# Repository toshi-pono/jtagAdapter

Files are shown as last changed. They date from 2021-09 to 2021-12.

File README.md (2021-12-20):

# JtagAdapter

jtag adapter using FT232H  
Created during the Security Camp 2021 X-2 track

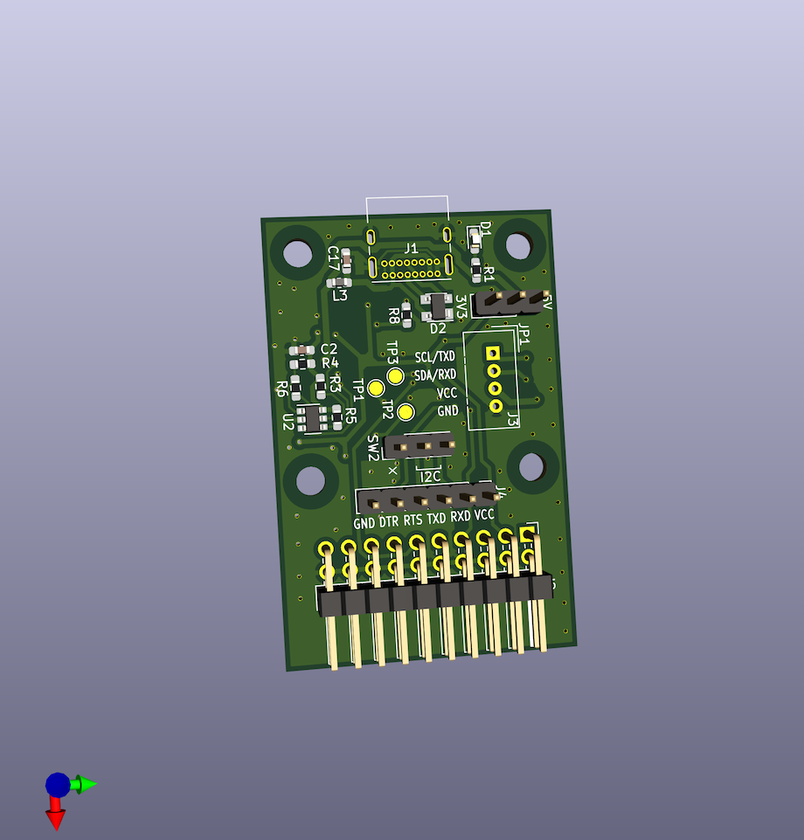
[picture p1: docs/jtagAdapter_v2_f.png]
JtagAdapter_v2_front
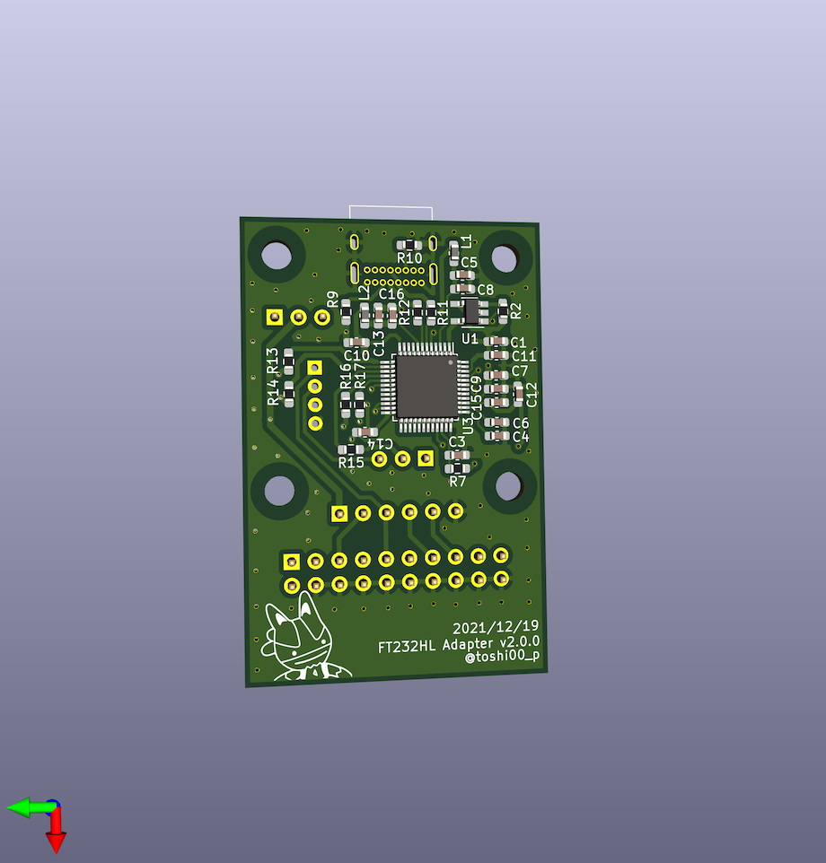
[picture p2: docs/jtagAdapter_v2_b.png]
JtagAdapter_v2_back


## License

SiT2001B-MEMS-Clock-Generator symbol is based on https://github.com/asukiaaa/kicad-symbols-asukiaaa

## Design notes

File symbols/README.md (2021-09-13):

Using https://github.com/asukiaaa/kicad-symbols-asukiaaa

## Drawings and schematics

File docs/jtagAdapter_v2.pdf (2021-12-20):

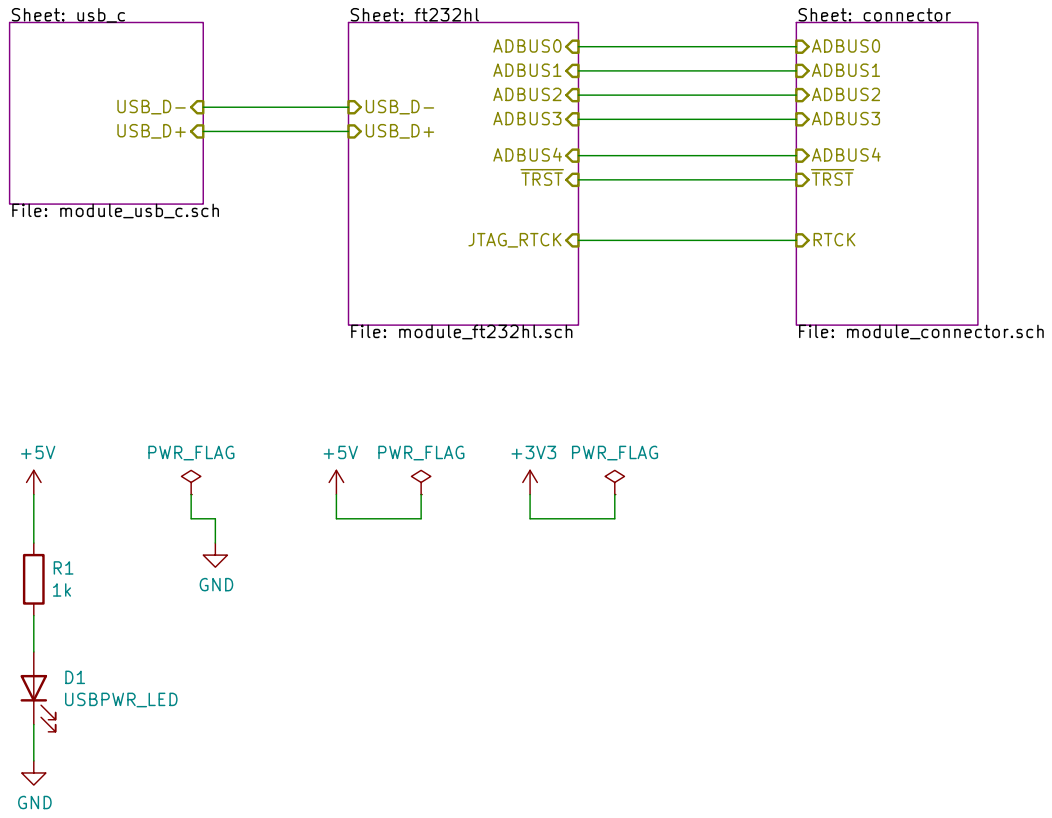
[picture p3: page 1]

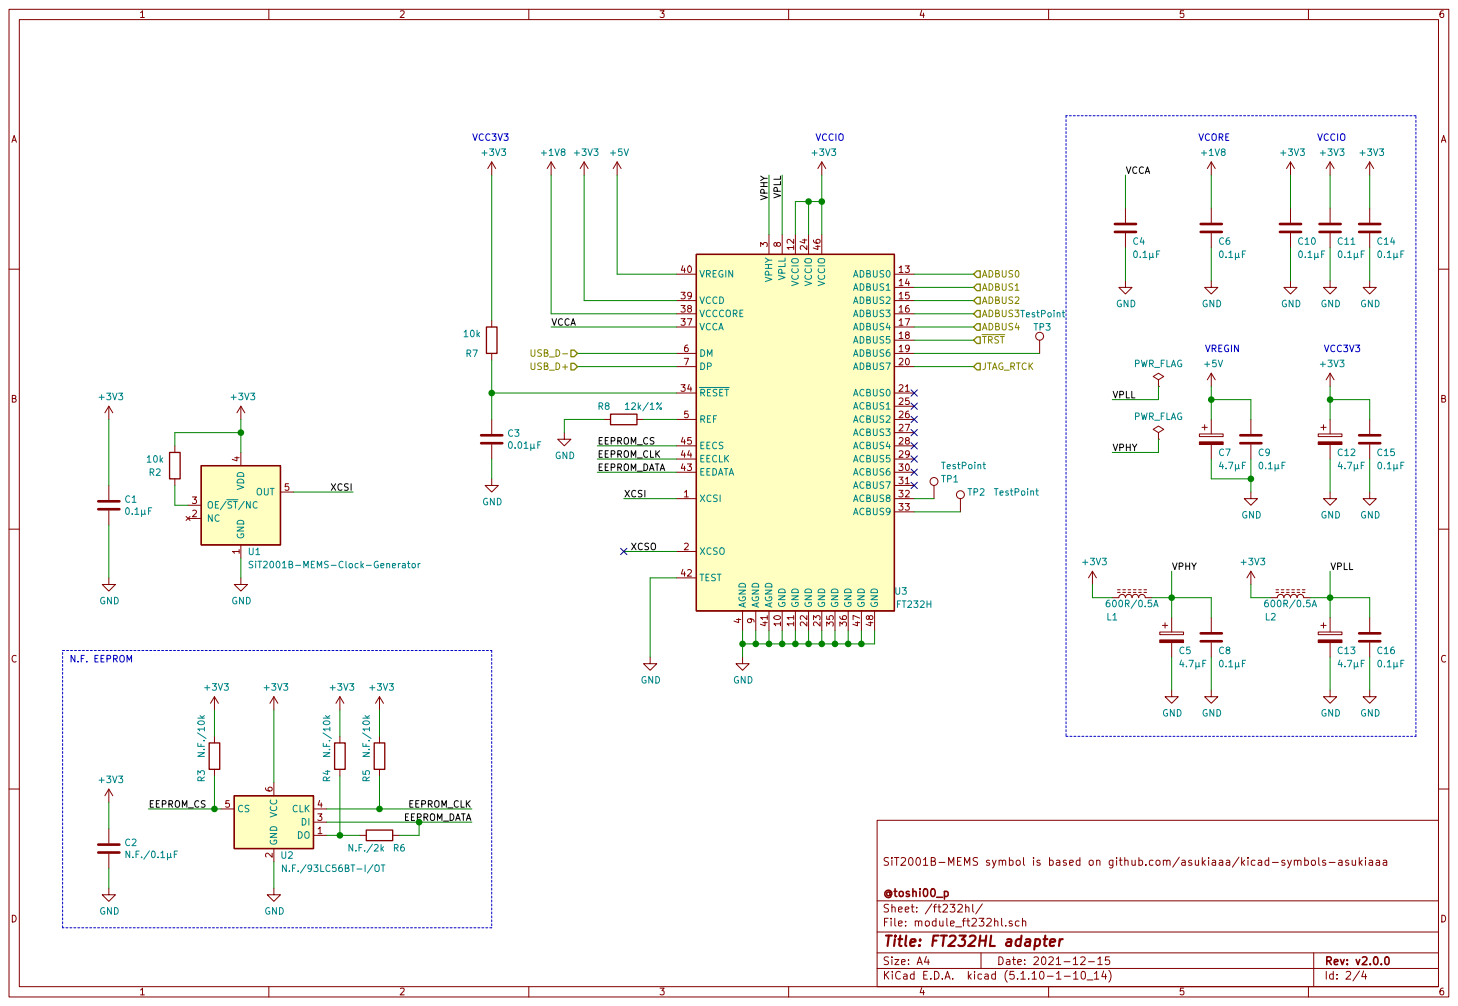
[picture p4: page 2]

4 VREGIN 40 AGND 41 TEST 42 EEDATA 43 EECLK 44 EECS 45 VCCIO 46 GND 47 GND 48 REF 5 DM 6 DP 7 VPLL

3 ACBUS6 30 ACBUS7 31 ACBUS8 32 ACBUS9 33 RESET 34 GND 35 GND 36 VCCA 37 VCCCORE 38 VCCD 39 AGND

4 OUT 5 U1SiT2001B-MEMS-Clock-Generator GND

1 NC 2 OE/ST/NC 3 VDD

SiT2001B-MEMS symbol is based on github.com/asukiaaa/kicad-symbols-asukiaaa GND

2 DI 3 CLK 4 CS 5 VCC

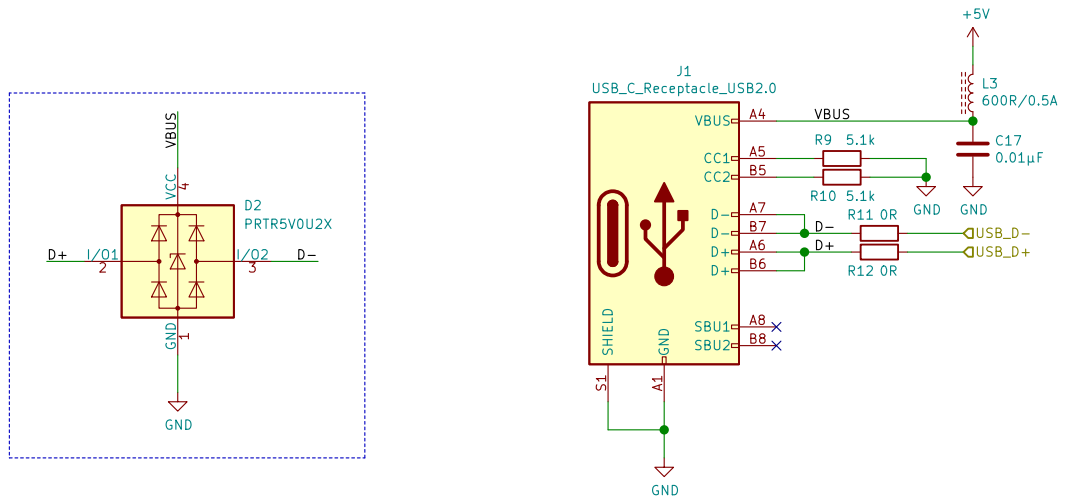
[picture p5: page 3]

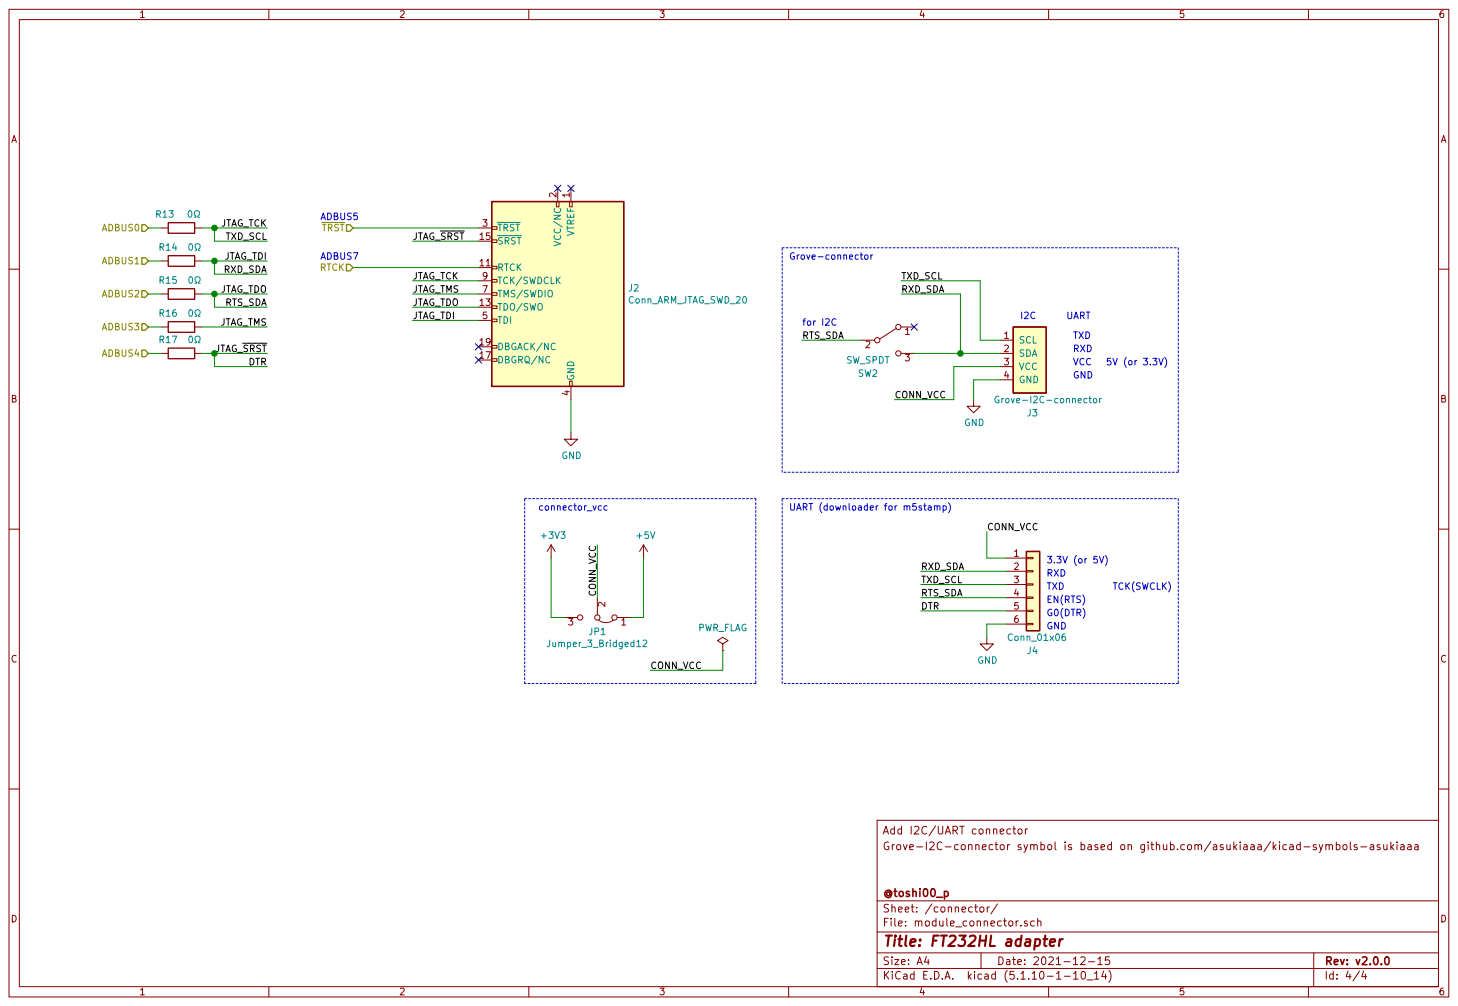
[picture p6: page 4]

1 RTCK 11 TDO/SWO 13 SRST 15 DBGRQ/NC 17 DBGACK/NC 19 VCC/NC

Grove-I2C-connector symbol is based on github.com/asukiaaa/kicad-symbols-asukiaaa Add I2C/UART connector VTREF

4 TDI 5 TMS/SWDIO 7 TCK/SWDCLK 9

File: module_connector.sch Sheet: /connector/ @toshi00_p

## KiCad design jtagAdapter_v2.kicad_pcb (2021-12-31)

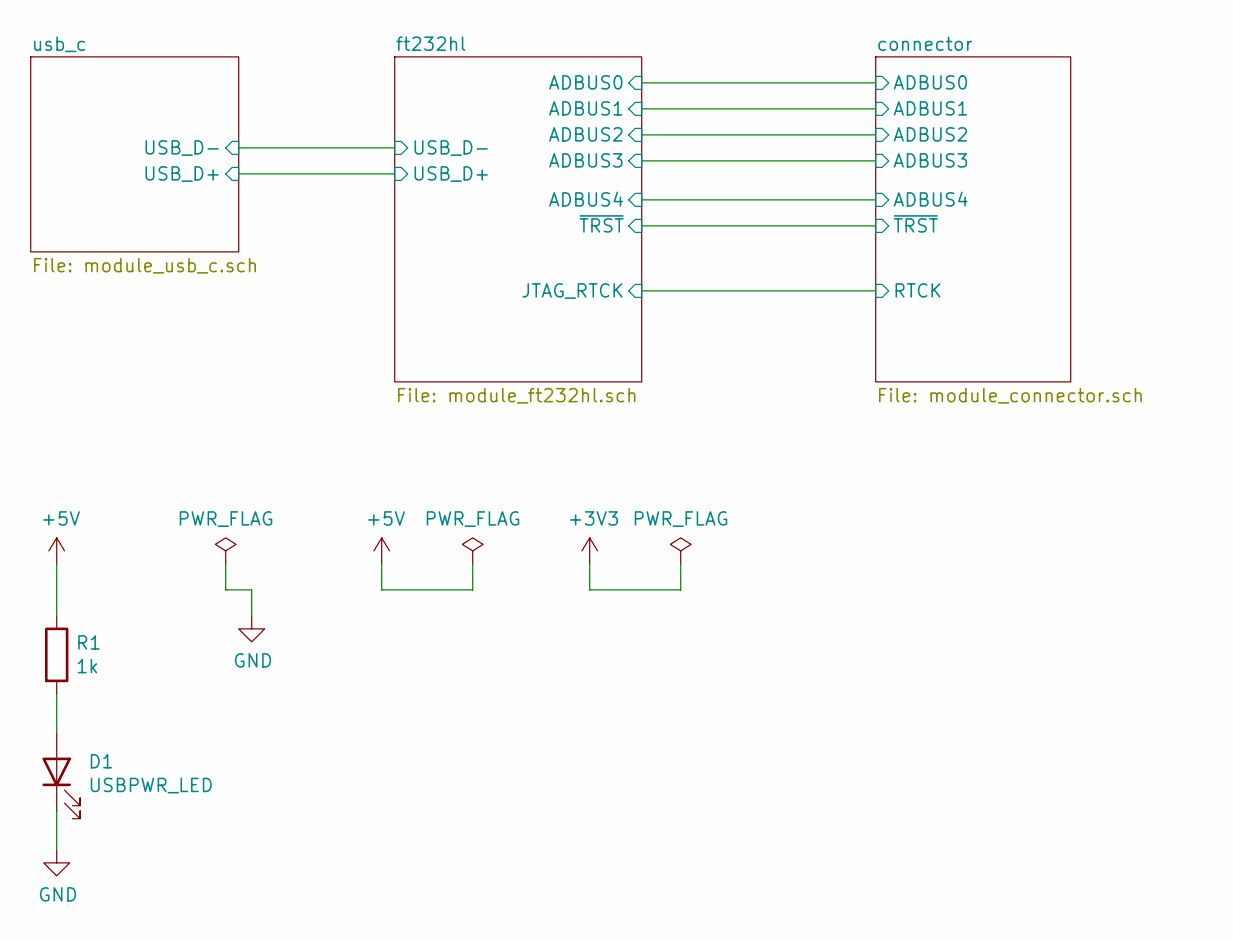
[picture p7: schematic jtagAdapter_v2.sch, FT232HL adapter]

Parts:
D1: USBPWR_LED; LED_0603_1608Metric_Pad1.05x0.95mm_HandSolder
R1: 1k; R_0603_1608Metric_Pad0.98x0.95mm_HandSolder

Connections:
+5V: R1.1; also elsewhere on the board
GND: D1.1 (K); also elsewhere on the board
unnamed: D1.2 (A), R1.2

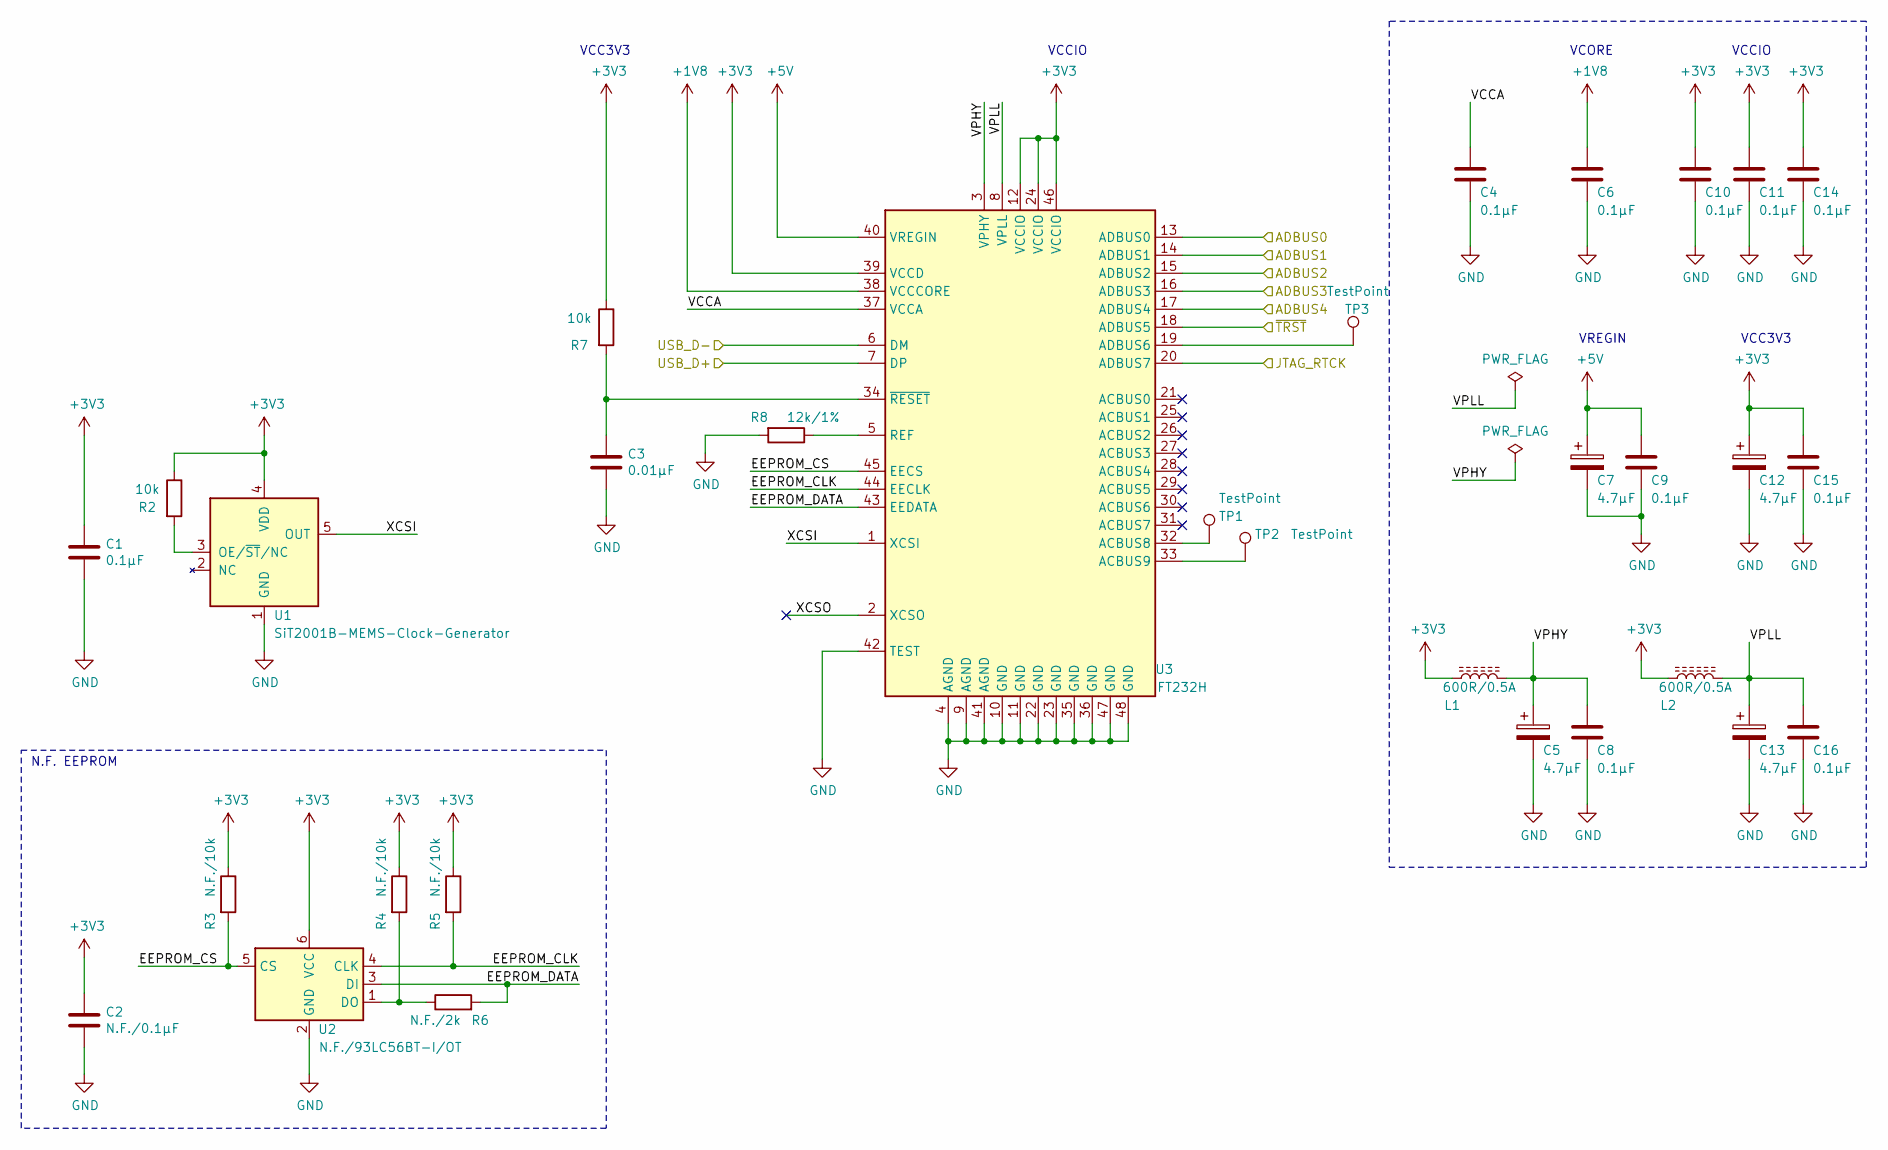
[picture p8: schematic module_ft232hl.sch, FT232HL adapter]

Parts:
C1, C4, C6, C8, C9, C10, C11, C14, C15, C16: 0.1μF; C_0603_1608Metric_Pad1.08x0.95mm_HandSolder
C2: N.F./0.1μF; C_0603_1608Metric_Pad1.08x0.95mm_HandSolder
C3: 0.01μF; C_0603_1608Metric_Pad1.08x0.95mm_HandSolder
C5, C7, C12, C13: 4.7μF; C_0603_1608Metric_Pad1.08x0.95mm_HandSolder
L1, L2: 600R/0.5A; L_0603_1608Metric_Pad1.05x0.95mm_HandSolder
R2, R7: 10k; R_0603_1608Metric_Pad0.98x0.95mm_HandSolder
R3, R4, R5: N.F./10k; R_0603_1608Metric_Pad0.98x0.95mm_HandSolder
R6: N.F./2k; R_0603_1608Metric_Pad0.98x0.95mm_HandSolder
R8: 12k/1%; R_0603_1608Metric_Pad0.98x0.95mm_HandSolder
TP1, TP2, TP3: TestPoint; TestPoint_Pad_D1.5mm
U1: SiT2001B-MEMS-Clock-Generator; SOT-23-5_HandSoldering
U2: N.F./93LC56BT-I/OT; SOT-23-6
U3: FT232H; LQFP-48_7x7mm_P0.5mm

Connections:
+1V8: C6.1, U3.38 (VCCCORE)
+3V3: C1.1, C2.1, C10.1, C11.1, C12.1, C14.1, C15.1, L1.1, L2.1, R2.1, R3.1, R4.1, R5.1, R7.1, U1.4 (VDD), U2.6 (VCC), U3.12 (VCCIO), U3.24 (VCCIO), U3.39 (VCCD), U3.46 (VCCIO); also elsewhere on the board
+5V: C7.1, C9.1, U3.40 (VREGIN); also elsewhere on the board
/connector/ADBUS0: U3.13 (ADBUS0); also elsewhere on the board
/connector/ADBUS1: U3.14 (ADBUS1); also elsewhere on the board
/connector/ADBUS2: U3.15 (ADBUS2); also elsewhere on the board
/connector/ADBUS3: U3.16 (ADBUS3); also elsewhere on the board
/connector/ADBUS4: U3.17 (ADBUS4); also elsewhere on the board
/connector/~TRST: U3.18 (ADBUS5); also elsewhere on the board
/ft232hl/EEPROM_CLK: R5.2, U2.4 (CLK), U3.44 (EECLK)
/ft232hl/EEPROM_CS: R3.2, U2.5 (CS), U3.45 (EECS)
/ft232hl/EEPROM_DATA: R6.2, U2.3 (DI), U3.43 (EEDATA)
/ft232hl/JTAG_RTCK: U3.20 (ADBUS7); also elsewhere on the board
/ft232hl/USB_D+: U3.7 (DP); also elsewhere on the board
/ft232hl/USB_D-: U3.6 (DM); also elsewhere on the board
/ft232hl/VCCA: C4.1, U3.37 (VCCA)
/ft232hl/VPHY: C5.1, C8.1, L1.2, U3.3 (VPHY)
/ft232hl/VPLL: C13.1, C16.1, L2.2, U3.8 (VPLL)
/ft232hl/XCSI: U1.5 (OUT), U3.1 (XCSI)
/ft232hl/XCSO: U3.2 (XCSO)
GND: C1.2, C2.2, C3.2, C4.2, C5.2, C6.2, C7.2, C8.2, C9.2, C10.2, C11.2, C12.2, C13.2, C14.2, C15.2, C16.2, R8.2, U1.1 (GND), U2.2 (GND), U3.4 (AGND), U3.9 (AGND), U3.10 (GND), U3.11 (GND), U3.22 (GND), U3.23 (GND), U3.35 (GND), U3.36 (GND), U3.41 (AGND), U3.42 (TEST), U3.47 (GND), U3.48 (GND); also elsewhere on the board
unnamed: C3.1, R7.2, U3.34 (~RESET)
unnamed: R2.2, U1.3 (OE/~ST~/NC)
unnamed: R4.2, R6.1, U2.1 (DO)
unnamed: R8.1, U3.5 (REF)
unnamed: TP1.1, U3.32 (ACBUS8)
unnamed: TP2.1, U3.33 (ACBUS9)
unnamed: TP3.1, U3.19 (ADBUS6)

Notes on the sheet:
N.F. EEPROM
VCCIO
VCORE
VCC3V3
VREGIN

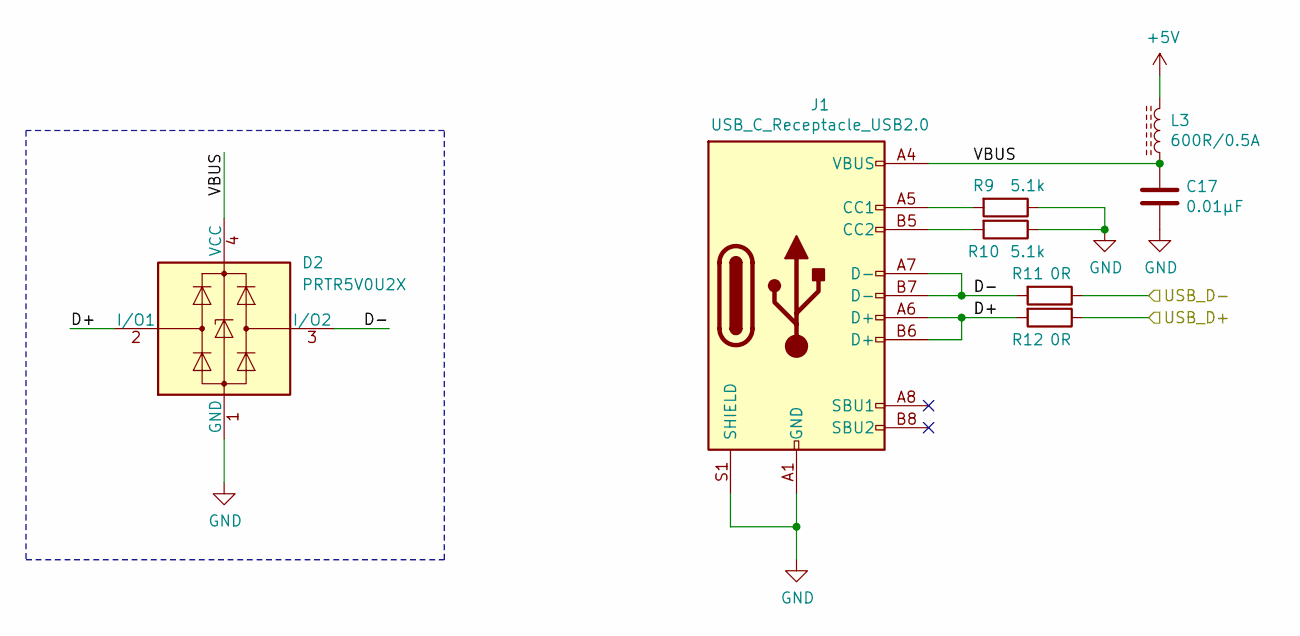
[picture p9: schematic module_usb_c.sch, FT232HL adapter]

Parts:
C17: 0.01μF; C_0603_1608Metric_Pad1.08x0.95mm_HandSolder
D2: PRTR5V0U2X; SOT-143
J1: USB_C_Receptacle_USB2.0; USB_C_Receptacle_GCT_USB4085
L3: 600R/0.5A; L_0603_1608Metric_Pad1.05x0.95mm_HandSolder
R9, R10: 5.1k; R_0603_1608Metric_Pad0.98x0.95mm_HandSolder
R11, R12: 0R; R_0603_1608Metric_Pad0.98x0.95mm_HandSolder

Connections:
+5V: L3.2; also elsewhere on the board
/ft232hl/USB_D+: R12.1; also elsewhere on the board
/ft232hl/USB_D-: R11.1; also elsewhere on the board
/usb_c/D+: D2.2 (I/O1), J1.A6 (D+), J1.B6 (D+), R12.2
/usb_c/D-: D2.3 (I/O2), J1.A7 (D-), J1.B7 (D-), R11.2
/usb_c/VBUS: C17.1, D2.4 (VCC), J1.A4 (VBUS), J1.A9 (VBUS), J1.B4 (VBUS), J1.B9 (VBUS), L3.1
GND: C17.2, D2.1 (GND), J1.A1 (GND), J1.A12 (GND), J1.B1 (GND), J1.B12 (GND), J1.S1 (SHIELD), R9.1, R10.1; also elsewhere on the board
unnamed: J1.A5 (CC1), R9.2
unnamed: J1.B5 (CC2), R10.2

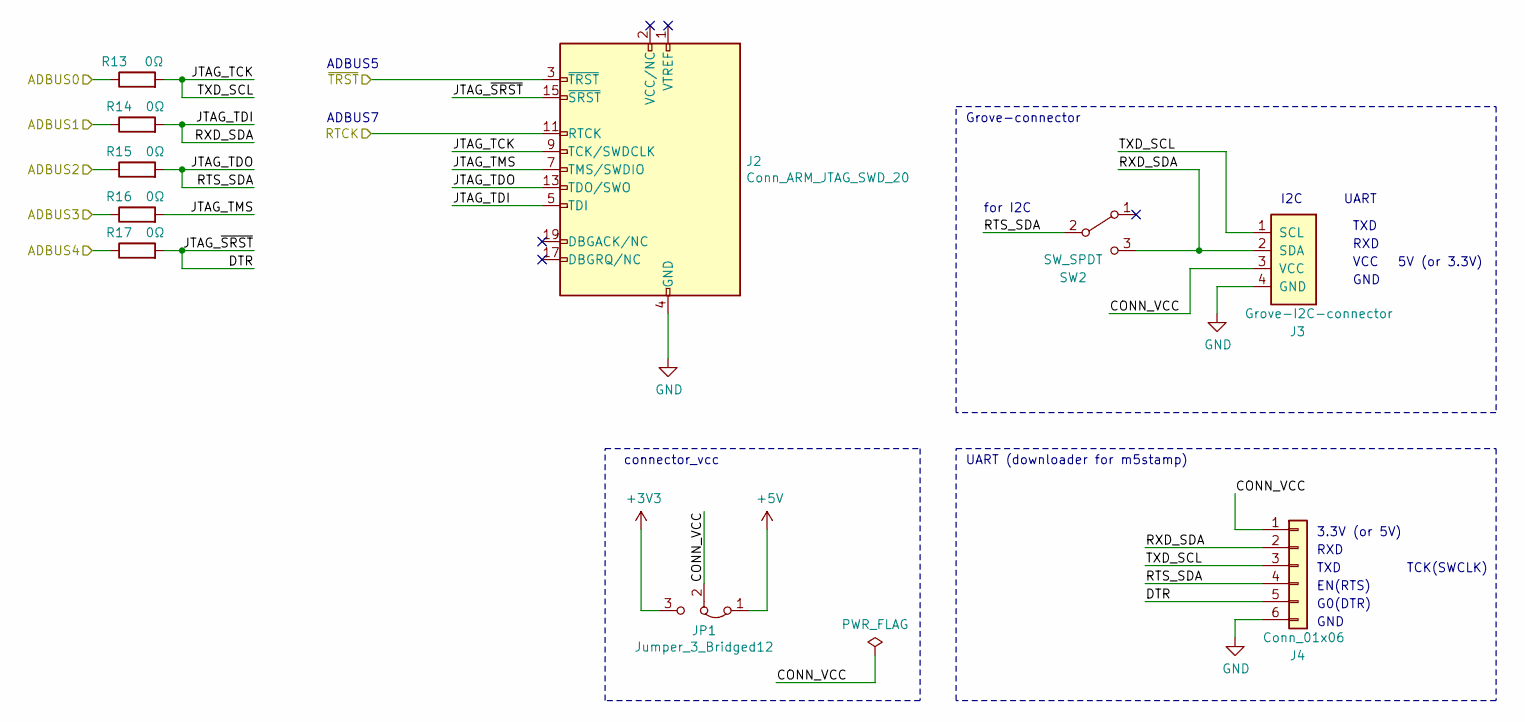
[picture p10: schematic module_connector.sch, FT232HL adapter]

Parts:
J2: Conn_ARM_JTAG_SWD_20; PinHeader_2x10_P2.54mm_Horizontal
J3: Grove-I2C-connector; NS-Tech_Grove_1x04_P2mm_Vertical
J4: Conn_01x06; PinHeader_1x06_P2.54mm_Vertical
JP1: Jumper_3_Bridged12; PinHeader_1x03_P2.54mm_Vertical
R13, R14, R15, R16, R17: 0Ω; R_0603_1608Metric_Pad0.98x0.95mm_HandSolder
SW2: SW_SPDT; PinHeader_1x03_P2.54mm_Vertical

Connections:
+3V3: JP1.3 (B); also elsewhere on the board
+5V: JP1.1 (A); also elsewhere on the board
/connector/ADBUS0: R13.1; also elsewhere on the board
/connector/ADBUS1: R14.1; also elsewhere on the board
/connector/ADBUS2: R15.1; also elsewhere on the board
/connector/ADBUS3: R16.1; also elsewhere on the board
/connector/ADBUS4: R17.1; also elsewhere on the board
/connector/CONN_VCC: J3.3 (VCC), J4.1, JP1.2 (C)
/connector/DTR: J2.15 (~SRST~), J4.5, R17.2
/connector/JTAG_TCK: J2.9 (TCK/SWDCLK), J3.1 (SCL), J4.3, R13.2
/connector/JTAG_TDI: J2.5 (TDI), J3.2 (SDA), J4.2, R14.2, SW2.3 (C)
/connector/JTAG_TDO: J2.13 (TDO/SWO), J4.4, R15.2, SW2.2 (B)
/connector/JTAG_TMS: J2.7 (TMS/SWDIO), R16.2
/connector/~TRST: J2.3 (~TRST~); also elsewhere on the board
/ft232hl/JTAG_RTCK: J2.11 (RTCK); also elsewhere on the board
GND: J2.4 (GND), J2.6 (GND), J2.8 (GND), J2.10 (GND), J2.12 (GND), J2.14 (GND), J2.16 (GND), J2.18 (GND), J2.20 (GND), J3.4 (GND), J4.6; also elsewhere on the board

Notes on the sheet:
I2C
UART
TXD
RXD
VCC
GND
Grove-connector
3.3V (or 5V)
EN(RTS)
G0(DTR)
UART (downloader for m5stamp)
connector_vcc
5V (or 3.3V)
for I2C
ADBUS5
ADBUS7
TCK(SWCLK)

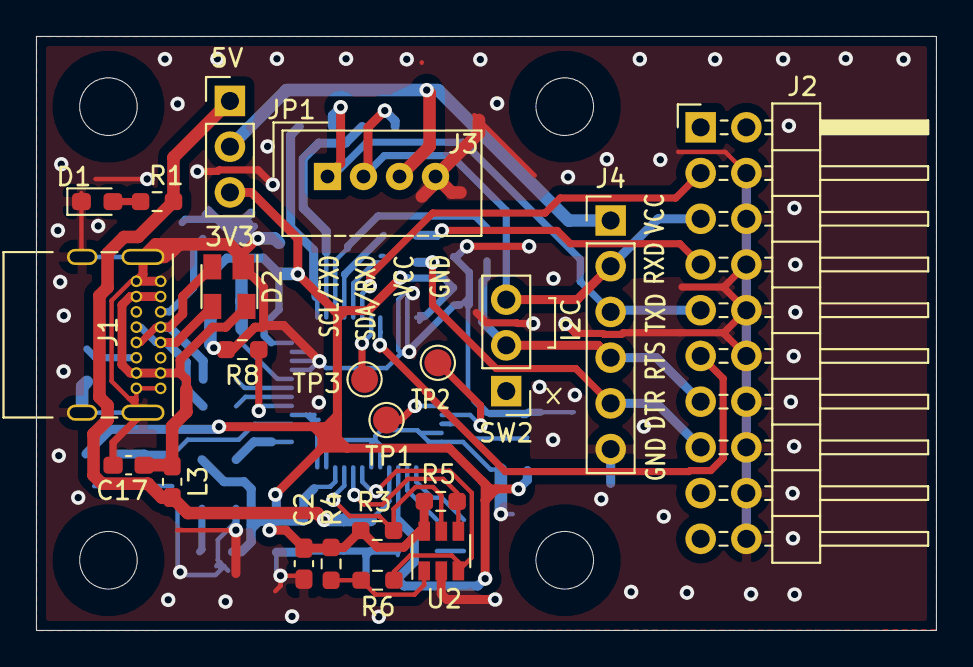
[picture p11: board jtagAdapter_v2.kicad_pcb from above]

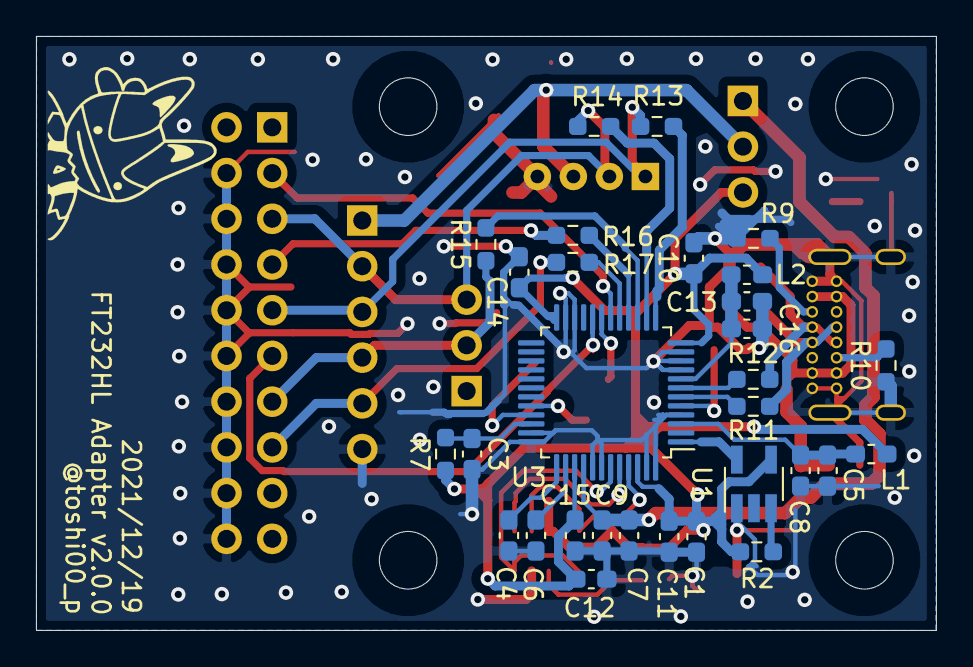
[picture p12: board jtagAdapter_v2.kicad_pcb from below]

Board: 2 copper layers, 50.0 x 33.0 mm, 51 parts (30 on the bottom side), 39 nets.

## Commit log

2021-09-13 remove unnecessary files
    [jtagAdapter.csv]
2021-12-20 .netファイルを削除
2021-12-20 v2.0.0を作成
    [jtagAdapter.kicad_pcb, jtagAdapter.sch, jtagAdapter_v2.kicad_pcb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]
2021-12-20 画像を追加
2021-12-20 サイズ調整
2021-12-20 画像を添付
2021-12-31 USB-Cフットプリントのエラーを修正
    [jtagAdapter_v2.kicad_pcb]
